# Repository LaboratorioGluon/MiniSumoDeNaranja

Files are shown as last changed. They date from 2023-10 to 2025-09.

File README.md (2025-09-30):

# MiniSumoDeNaranja
Minisumo para la competición OSHDEM 2023.

Hecho integramente en los directos de twitch (www.twitch.tv/labgluon)

# Hardware

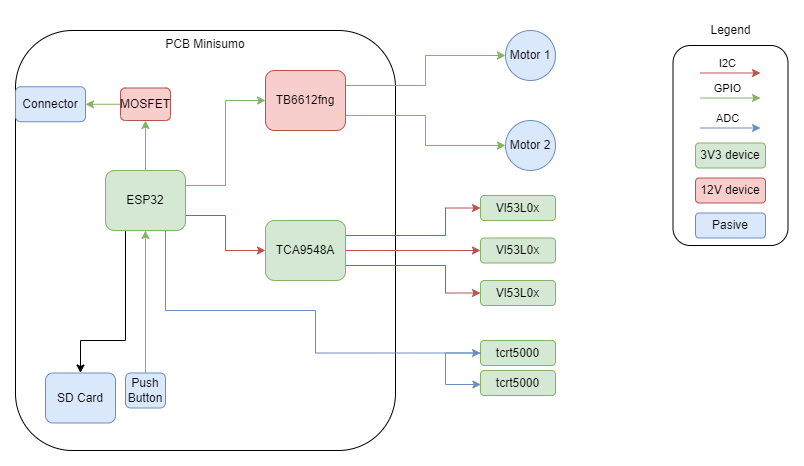
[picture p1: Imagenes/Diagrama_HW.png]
Diagrama HW


## Componentes (fuera de la PCB):
- Sensores IR (TCRT5000) https://s.click.aliexpress.com/e/_DeqiwYr
- Sensores ToF (VL53L0X) https://s.click.aliexpress.com/e/_DDpGy5Z
- Motores (N20 200RPM) https://s.click.aliexpress.com/e/_DkiL8JH
- ESP32 (ESP32-WROOM-32D) https://s.click.aliexpress.com/e/_DlMmuSj

## Configuracion pines

| 1 | 2 | 3 | 4 | Modo |
|-|-|-|-|-|
| 0 | 0 | 0 | 0 | FWD  |
| 1 | 0 | 0 | 0 | RIGHT|
| 0 | 1 | 0 | 0 | LEFT |

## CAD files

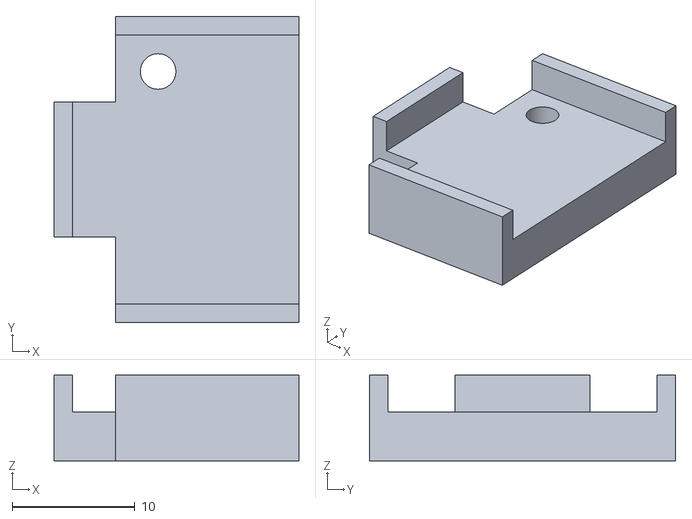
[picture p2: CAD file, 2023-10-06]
3D/Sujeccion_Alimentacion.stl
20.0 x 25.0 x 7.00

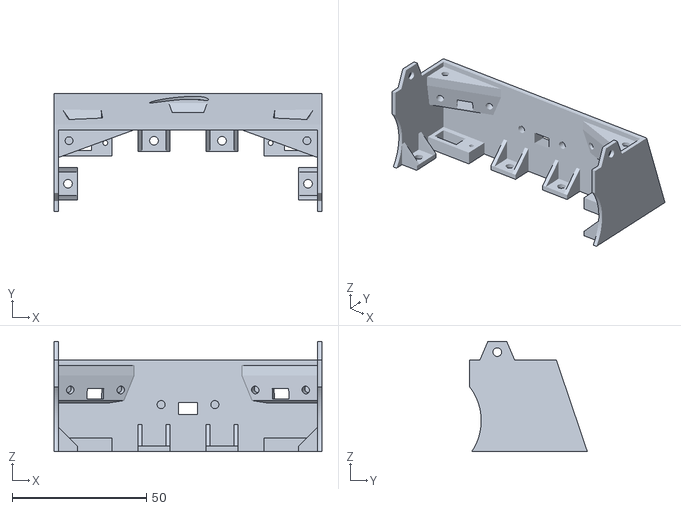
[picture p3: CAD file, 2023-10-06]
3D/Frontal.stl
99.7 x 43.8 x 41.0

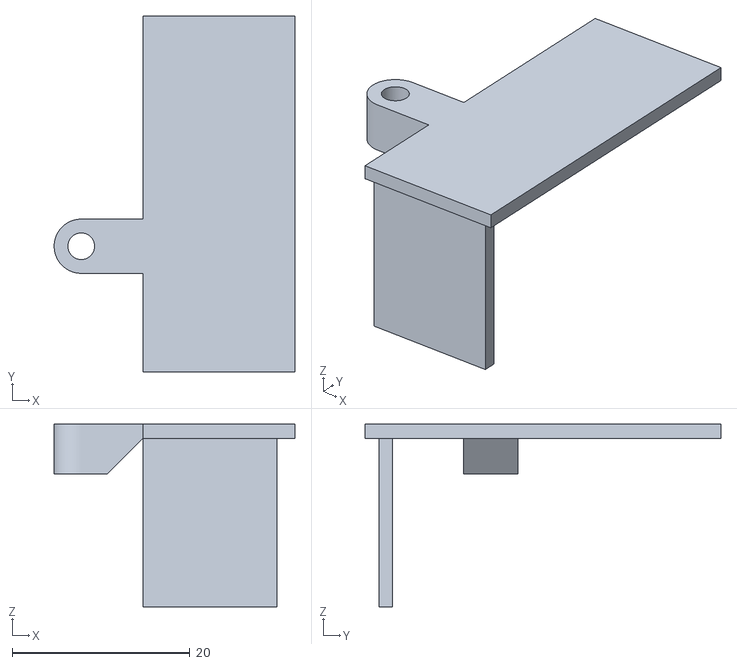
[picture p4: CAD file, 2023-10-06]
3D/SujeccionBateria.stl
27.1 x 40.1 x 20.6

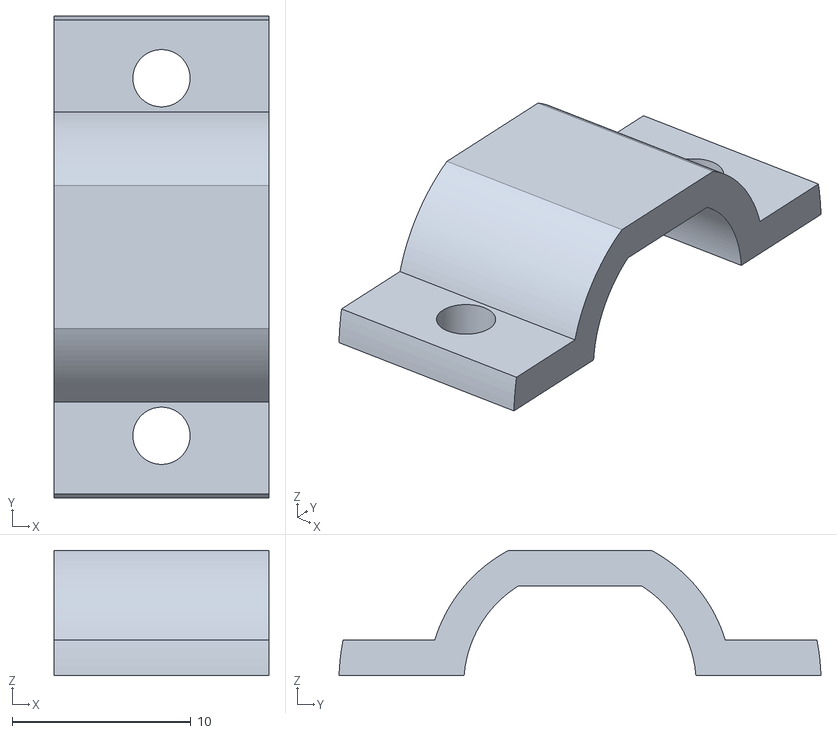
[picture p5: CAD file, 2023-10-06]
3D/Base_N20_Holder.stl
12.0 x 27.0 x 7.00

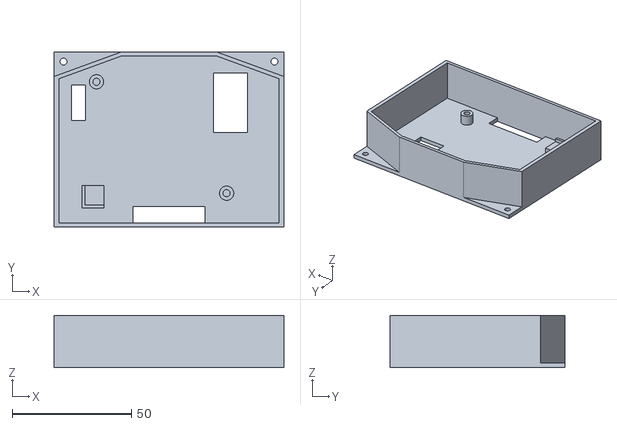
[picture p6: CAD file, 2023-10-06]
3D/Superior.stl
96.5 x 73.4 x 22.0

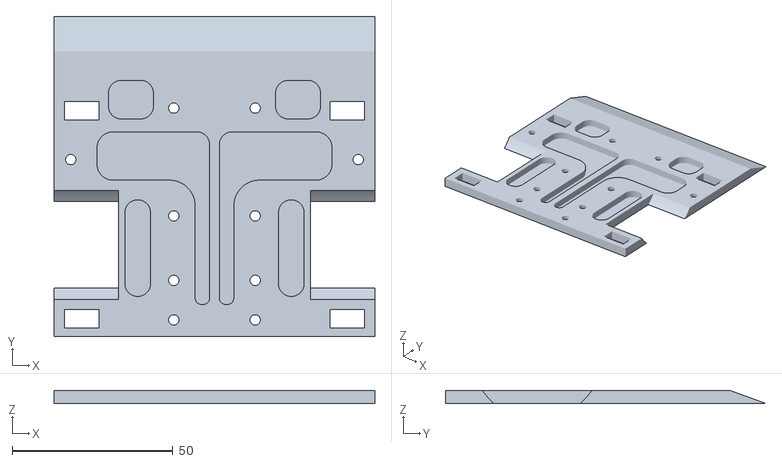
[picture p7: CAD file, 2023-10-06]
3D/Base_bottom.stl
99.7 x 99.5 x 4.00

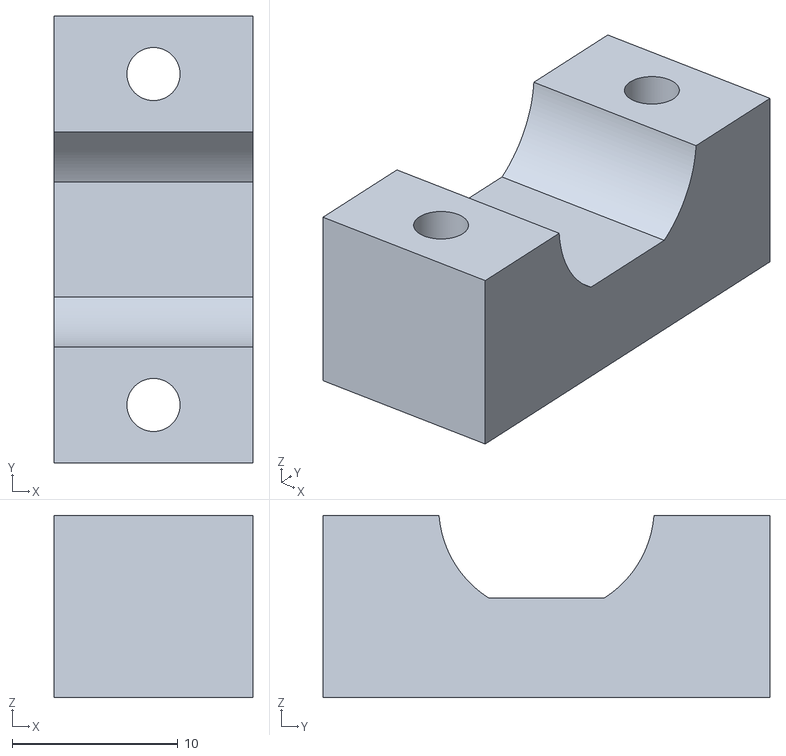
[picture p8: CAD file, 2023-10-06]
3D/Base_N20_Base.stl
12.0 x 27.0 x 11.0

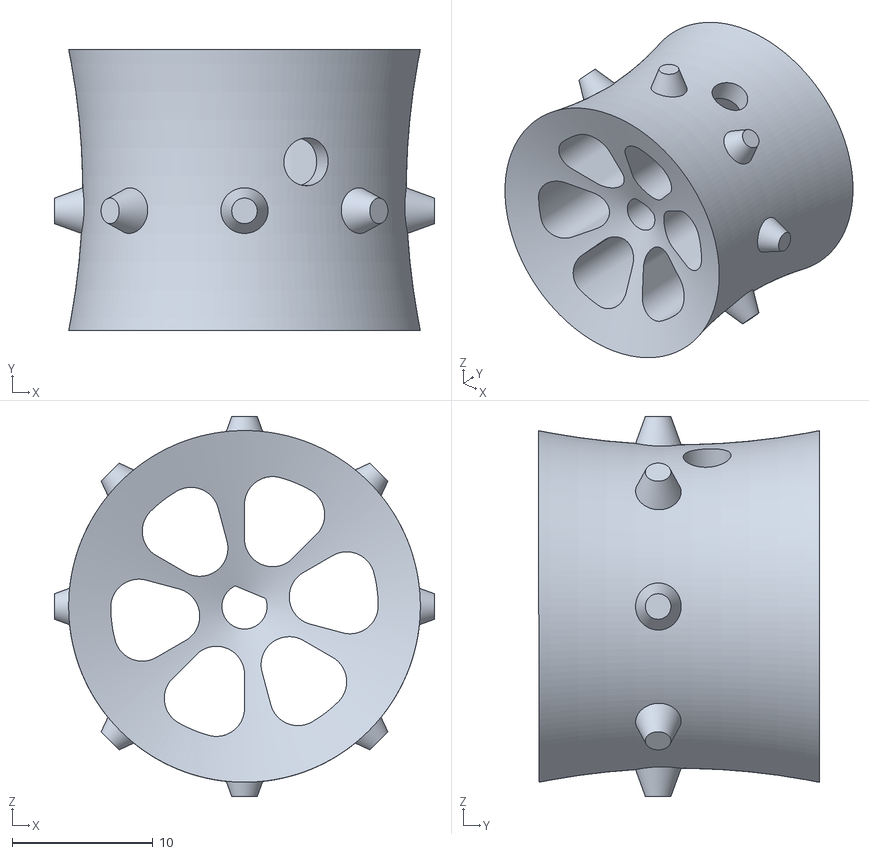
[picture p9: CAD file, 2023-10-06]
3D/Rueda - Llanta.stl
27.0 x 20.0 x 27.0

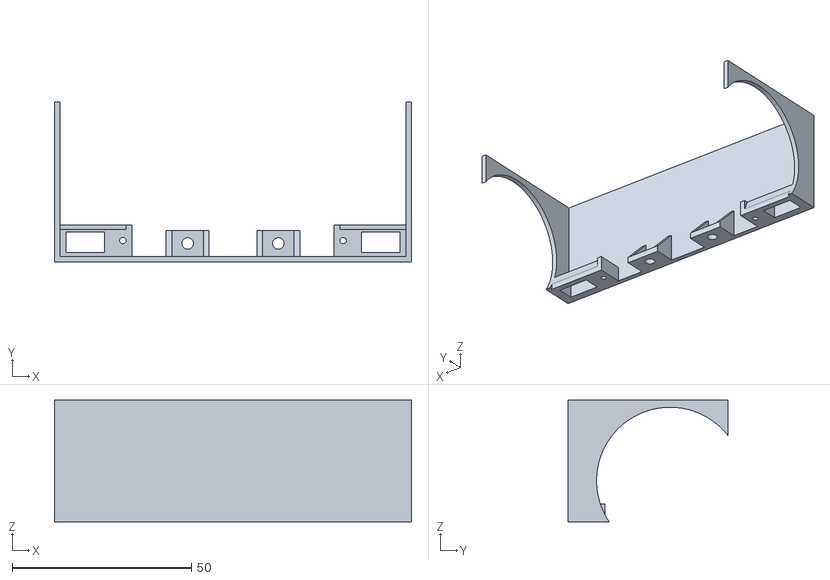
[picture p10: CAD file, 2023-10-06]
3D/Trasera.stl
99.7 x 44.7 x 34.0

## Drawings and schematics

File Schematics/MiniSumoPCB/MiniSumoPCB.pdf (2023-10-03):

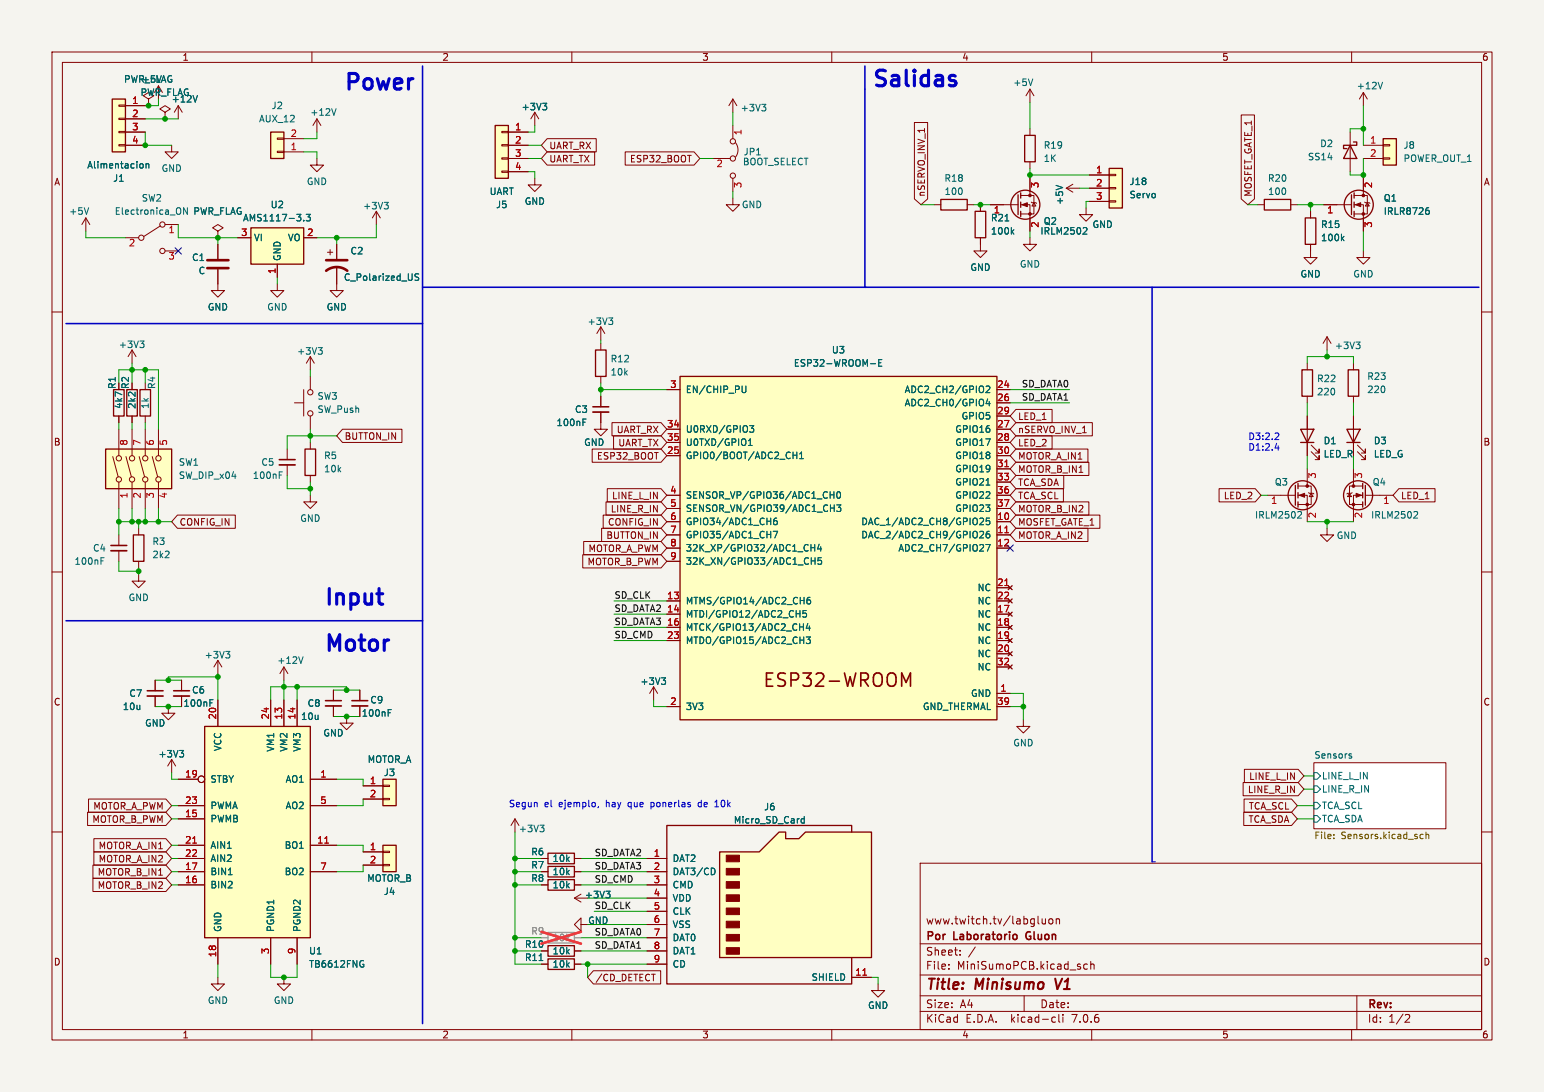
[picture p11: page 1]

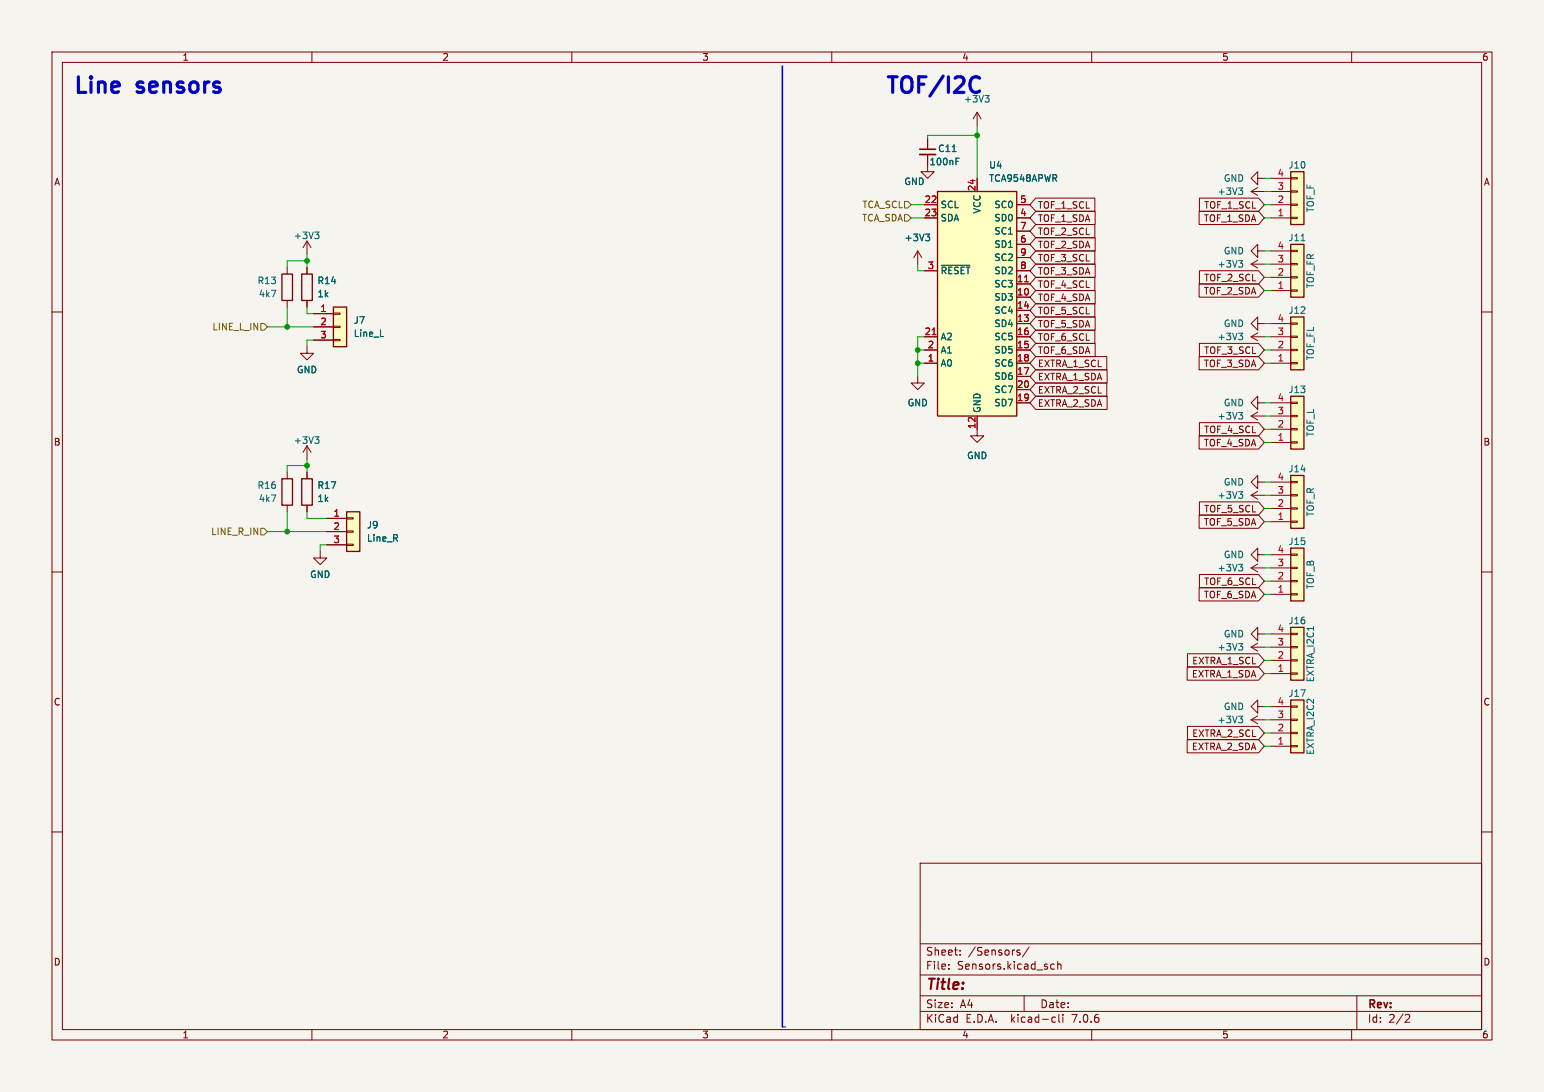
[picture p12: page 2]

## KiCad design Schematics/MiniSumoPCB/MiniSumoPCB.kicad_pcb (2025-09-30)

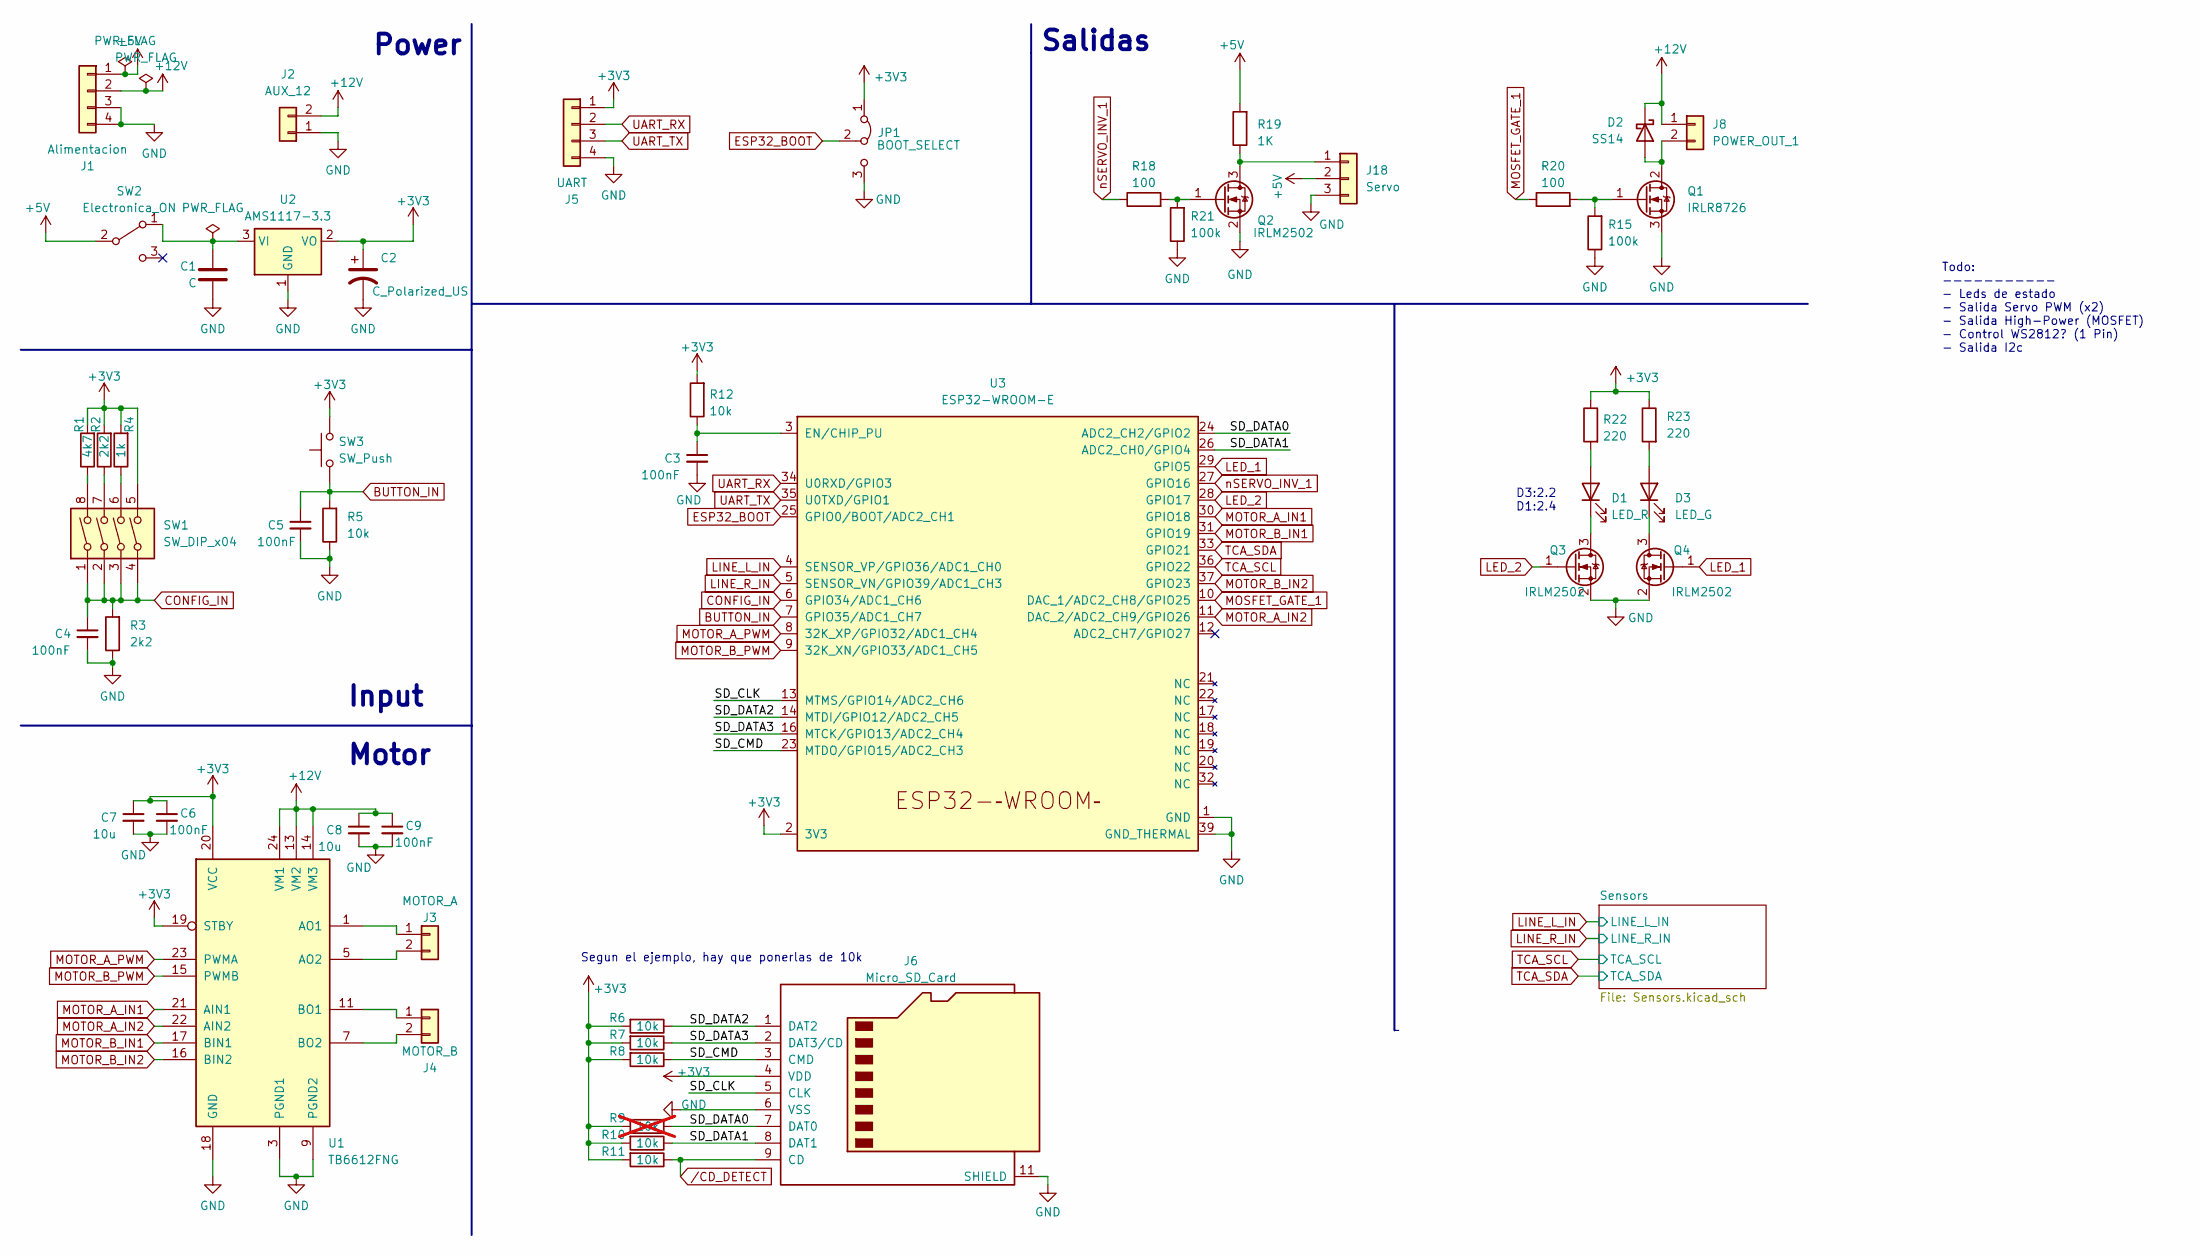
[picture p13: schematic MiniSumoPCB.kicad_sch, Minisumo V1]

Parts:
C1: C; C_1206_3216Metric_Pad1.33x1.80mm_HandSolder
C2: C_Polarized_US; CP_Elec_4x5.3
C3, C4, C5, C6, C9: 100nF; C_1206_3216Metric_Pad1.33x1.80mm_HandSolder
C7, C8: 10u; C_1206_3216Metric_Pad1.33x1.80mm_HandSolder
D1: LED_R; LED_1210_3225Metric_Pad1.42x2.65mm_HandSolder
D2: SS14; D_SMA_Handsoldering
D3: LED_G; LED_1210_3225Metric_Pad1.42x2.65mm_HandSolder
J1: Alimentacion; JST_PH_B4B-PH-K_1x04_P2.00mm_Vertical
J2: AUX_12; S2B-XH-SM4-TB
J3: MOTOR_A; S2B-XH-SM4-TB
J4: MOTOR_B; S2B-XH-SM4-TB
J5: UART; PinHeader_1x04_P2.54mm_Vertical
J6: Micro_SD_Card; microSD-Receptacle-SelfEject
J8: POWER_OUT_1; S2B-XH-SM4-TB
J18: Servo; PinHeader_1x03_P2.54mm_Vertical
JP1: BOOT_SELECT; PinHeader_1x03_P2.54mm_Vertical
Q1: IRLR8726; TO-252-2
Q2, Q3, Q4: IRLM2502; SOT-23
R1: 4k7; R_1206_3216Metric_Pad1.30x1.75mm_HandSolder
R2, R3: 2k2; R_1206_3216Metric_Pad1.30x1.75mm_HandSolder
R4: 1k; R_1206_3216Metric_Pad1.30x1.75mm_HandSolder
R5, R6, R7, R8, R10, R11, R12: 10k; R_1206_3216Metric_Pad1.30x1.75mm_HandSolder
R9: 10k; R_1206_3216Metric_Pad1.30x1.75mm_HandSolder; not fitted
R15, R21: 100k; R_1206_3216Metric_Pad1.30x1.75mm_HandSolder
R18, R20: 100; R_1206_3216Metric_Pad1.30x1.75mm_HandSolder
R19: 1K; R_1206_3216Metric_Pad1.30x1.75mm_HandSolder
R22, R23: 220; R_1206_3216Metric_Pad1.30x1.75mm_HandSolder
SW1: SW_DIP_x04; SW_DIP_SPSTx04_Slide_9.78x12.34mm_W7.62mm_P2.54mm
SW2: Electronica_ON; SS12D07VG2
SW3: SW_Push; SKPMANE010 _Silicone_6x6mm
U1: TB6612FNG; SSOP-24_5.3x8.2mm_P0.65mm
U2: AMS1117-3.3; SOT-223-3_TabPin2
U3: ESP32-WROOM-E; ESP32-WROOM-32E

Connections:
+3V3: C2.1, C6.1, C7.1, J5.1, J6.4 (VDD), JP1.1 (A), R1.2, R2.2, R4.2, R6.2, R7.2, R8.2, R9.2, R10.2, R11.2, R12.2, R22.1, R23.1, SW1.5, SW3.2, U1.19 (STBY), U1.20 (VCC), U2.2 (VO), U3.2 (3V3); also elsewhere on the board
+5V: J1.1, J18.2, R19.2, SW2.2 (B)
+12V: C8.1, C9.1, D2.1 (K), J1.2, J2.2, J8.1, U1.13 (VM2), U1.14 (VM3), U1.24 (VM1)
/SD_CLK: J6.5 (CLK), U3.13 (MTMS/GPIO14/ADC2_CH6)
/SD_CMD: J6.3 (CMD), R8.1, U3.23 (MTDO/GPIO15/ADC2_CH3)
/SD_DATA0: J6.7 (DAT0), R9.1, U3.24 (ADC2_CH2/GPIO2)
/SD_DATA1: J6.8 (DAT1), R10.1, U3.26 (ADC2_CH0/GPIO4)
/SD_DATA2: J6.1 (DAT2), R6.1, U3.14 (MTDI/GPIO12/ADC2_CH5)
/SD_DATA3: J6.2 (DAT3/CD), R7.1, U3.16 (MTCK/GPIO13/ADC2_CH4)
BUTTON_IN: C5.1, R5.2, SW3.1, U3.7 (GPIO35/ADC1_CH7)
CONFIG_IN: C4.1, R3.2, SW1.1, SW1.2, SW1.3, SW1.4, U3.6 (GPIO34/ADC1_CH6)
ESP32_BOOT: JP1.2 (C), U3.25 (GPIO0/BOOT/ADC2_CH1)
GND: C1.2, C2.2, C3.2, C4.2, C5.2, C6.2, C7.2, C8.2, C9.2, J1.3, J1.4, J2.1, J5.4, J6.6 (VSS), J6.11 (SHIELD), J18.3, JP1.3 (B), Q1.3 (S), Q2.2 (S), Q3.2 (S), Q4.2 (S), R3.1, R5.1, R15.1, R21.1, U1.3 (PGND1), U1.4 (PGND1), U1.9 (PGND2), U1.10 (PGND2), U1.18 (GND), U2.1 (GND), U3.1 (GND), U3.15 (GND), U3.38 (GND), U3.39 (GND_THERMAL); also elsewhere on the board
LED_1: Q4.1 (G), U3.29 (GPIO5)
LED_2: Q3.1 (G), U3.28 (GPIO17)
LINE_L_IN: U3.4 (SENSOR_VP/GPIO36/ADC1_CH0); also elsewhere on the board
LINE_R_IN: U3.5 (SENSOR_VN/GPIO39/ADC1_CH3); also elsewhere on the board
MOSFET_GATE_1: R20.1, U3.10 (DAC_1/ADC2_CH8/GPIO25)
MOTOR_A_IN1: U1.21 (AIN1), U3.30 (GPIO18)
MOTOR_A_IN2: U1.22 (AIN2), U3.11 (DAC_2/ADC2_CH9/GPIO26)
MOTOR_A_PWM: U1.23 (PWMA), U3.8 (32K_XP/GPIO32/ADC1_CH4)
MOTOR_B_IN1: U1.17 (BIN1), U3.31 (GPIO19)
MOTOR_B_IN2: U1.16 (BIN2), U3.37 (GPIO23)
MOTOR_B_PWM: U1.15 (PWMB), U3.9 (32K_XN/GPIO33/ADC1_CH5)
unnamed: D1.2 (A), R22.2
unnamed: D1.1 (K), Q3.3 (D)
unnamed: D2.2 (A), J8.2, Q1.2 (D)
unnamed: D3.2 (A), R23.2
unnamed: D3.1 (K), Q4.3 (D)
unnamed: J3.1, U1.1 (AO1), U1.2 (AO1)
unnamed: J3.2, U1.5 (AO2), U1.6 (AO2)
unnamed: J4.1, U1.11 (BO1), U1.12 (BO1)
unnamed: J4.2, U1.7 (BO2), U1.8 (BO2)
unnamed: J18.1, Q2.3 (D), R19.1
unnamed: Q1.1 (G), R15.2, R20.2
unnamed: Q2.1 (G), R18.2, R21.2
unnamed: R1.1, SW1.8
unnamed: R2.1, SW1.7
unnamed: R4.1, SW1.6
unnamed: C1.1, SW2.1 (A), U2.3 (VI)
unnamed: C3.1, R12.1, U3.3 (EN/CHIP_PU)
TCA_SCL: U3.36 (GPIO22); also elsewhere on the board
TCA_SDA: U3.33 (GPIO21); also elsewhere on the board
UART_RX: J5.2, U3.34 (U0RXD/GPIO3)
UART_TX: J5.3, U3.35 (U0TXD/GPIO1)
nSERVO_INV_1: R18.1, U3.27 (GPIO16)
/CD_DETECT: J6.9 (CD), R11.1

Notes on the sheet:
Motor
Segun el ejemplo, hay que ponerlas de 10k
Power
Salidas
D3:2.2 D1:2.4
Todo: ----------- - Leds de estado - Salida Servo PWM (x2) - Salida High-Power (MOSFET) - Control WS2812? (1 Pin) - Salida I2c
Input

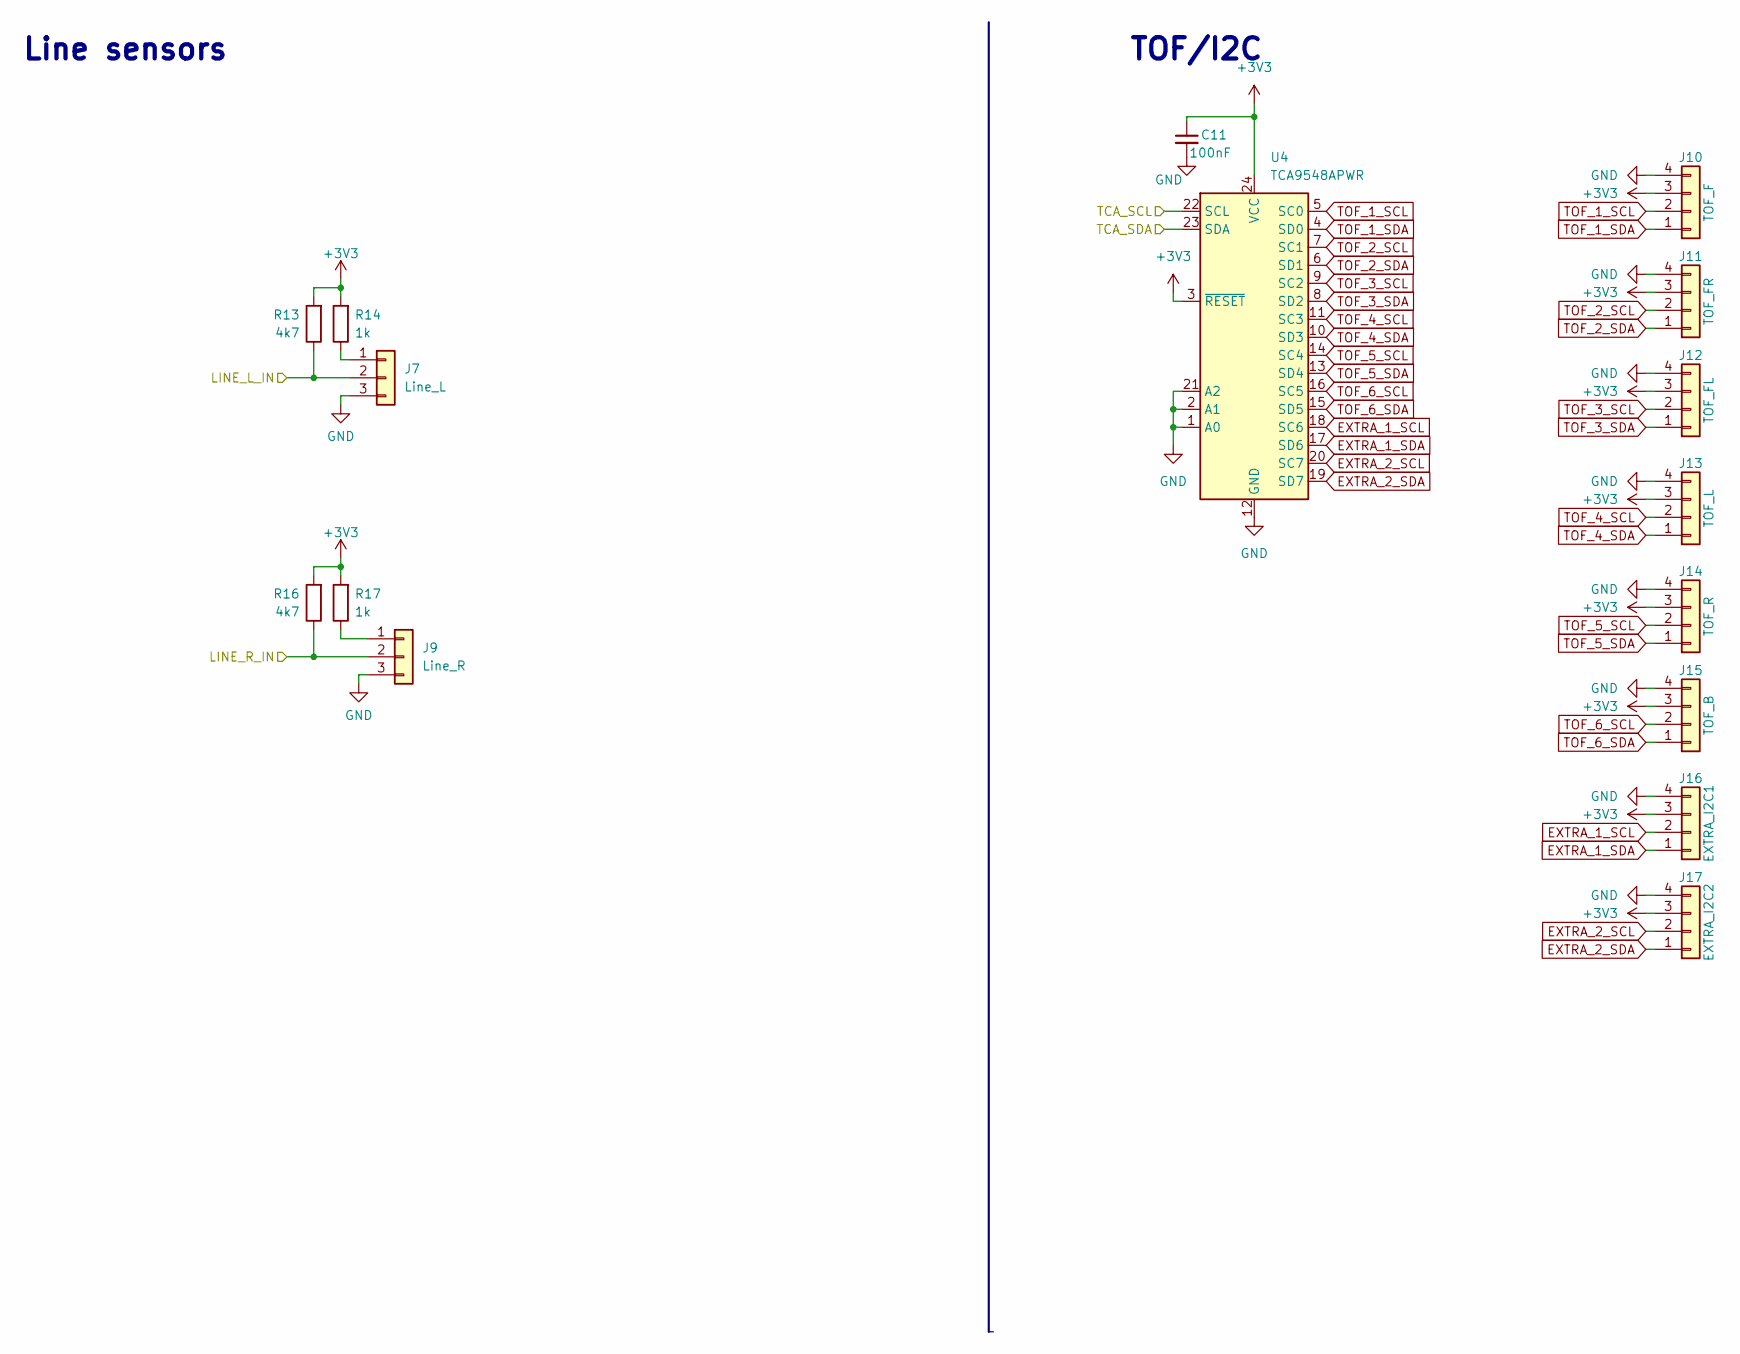
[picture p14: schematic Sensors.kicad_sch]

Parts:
C11: 100nF; C_1206_3216Metric_Pad1.33x1.80mm_HandSolder
J7: Line_L; JST_PH_B3B-PH-K_1x03_P2.00mm_Vertical
J9: Line_R; JST_PH_B3B-PH-K_1x03_P2.00mm_Vertical
J10: TOF_F; JST_PH_B4B-PH-K_1x04_P2.00mm_Vertical
J11: TOF_FR; JST_PH_B4B-PH-K_1x04_P2.00mm_Vertical
J12: TOF_FL; JST_PH_B4B-PH-K_1x04_P2.00mm_Vertical
J13: TOF_L; JST_PH_B4B-PH-K_1x04_P2.00mm_Vertical
J14: TOF_R; JST_PH_B4B-PH-K_1x04_P2.00mm_Vertical
J15: TOF_B; JST_PH_B4B-PH-K_1x04_P2.00mm_Vertical
J16: EXTRA_I2C1; JST_PH_B4B-PH-K_1x04_P2.00mm_Vertical
J17: EXTRA_I2C2; JST_PH_B4B-PH-K_1x04_P2.00mm_Vertical
R13, R16: 4k7; R_1206_3216Metric_Pad1.30x1.75mm_HandSolder
R14, R17: 1k; R_1206_3216Metric_Pad1.30x1.75mm_HandSolder
U4: TCA9548APWR; TSSOP-24_4.4x7.8mm_P0.65mm

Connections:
+3V3: C11.1, J10.3, J11.3, J12.3, J13.3, J14.3, J15.3, J16.3, J17.3, R13.2, R14.2, R16.2, R17.2, U4.3 (~RESET), U4.24 (VCC); also elsewhere on the board
EXTRA_1_SCL: J16.2, U4.18 (SC6)
EXTRA_1_SDA: J16.1, U4.17 (SD6)
EXTRA_2_SCL: J17.2, U4.20 (SC7)
EXTRA_2_SDA: J17.1, U4.19 (SD7)
GND: C11.2, J7.3, J9.3, J10.4, J11.4, J12.4, J13.4, J14.4, J15.4, J16.4, J17.4, U4.1 (A0), U4.2 (A1), U4.12 (GND), U4.21 (A2); also elsewhere on the board
LINE_L_IN: J7.2, R13.1; also elsewhere on the board
LINE_R_IN: J9.2, R16.1; also elsewhere on the board
unnamed: J7.1, R14.1
unnamed: J9.1, R17.1
TCA_SCL: U4.22 (SCL); also elsewhere on the board
TCA_SDA: U4.23 (SDA); also elsewhere on the board
TOF_1_SCL: J10.2, U4.5 (SC0)
TOF_1_SDA: J10.1, U4.4 (SD0)
TOF_2_SCL: J11.2, U4.7 (SC1)
TOF_2_SDA: J11.1, U4.6 (SD1)
TOF_3_SCL: J12.2, U4.9 (SC2)
TOF_3_SDA: J12.1, U4.8 (SD2)
TOF_4_SCL: J13.2, U4.11 (SC3)
TOF_4_SDA: J13.1, U4.10 (SD3)
TOF_5_SCL: J14.2, U4.14 (SC4)
TOF_5_SDA: J14.1, U4.13 (SD4)
TOF_6_SCL: J15.2, U4.16 (SC5)
TOF_6_SDA: J15.1, U4.15 (SD5)

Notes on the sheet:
Line sensors
TOF/I2C

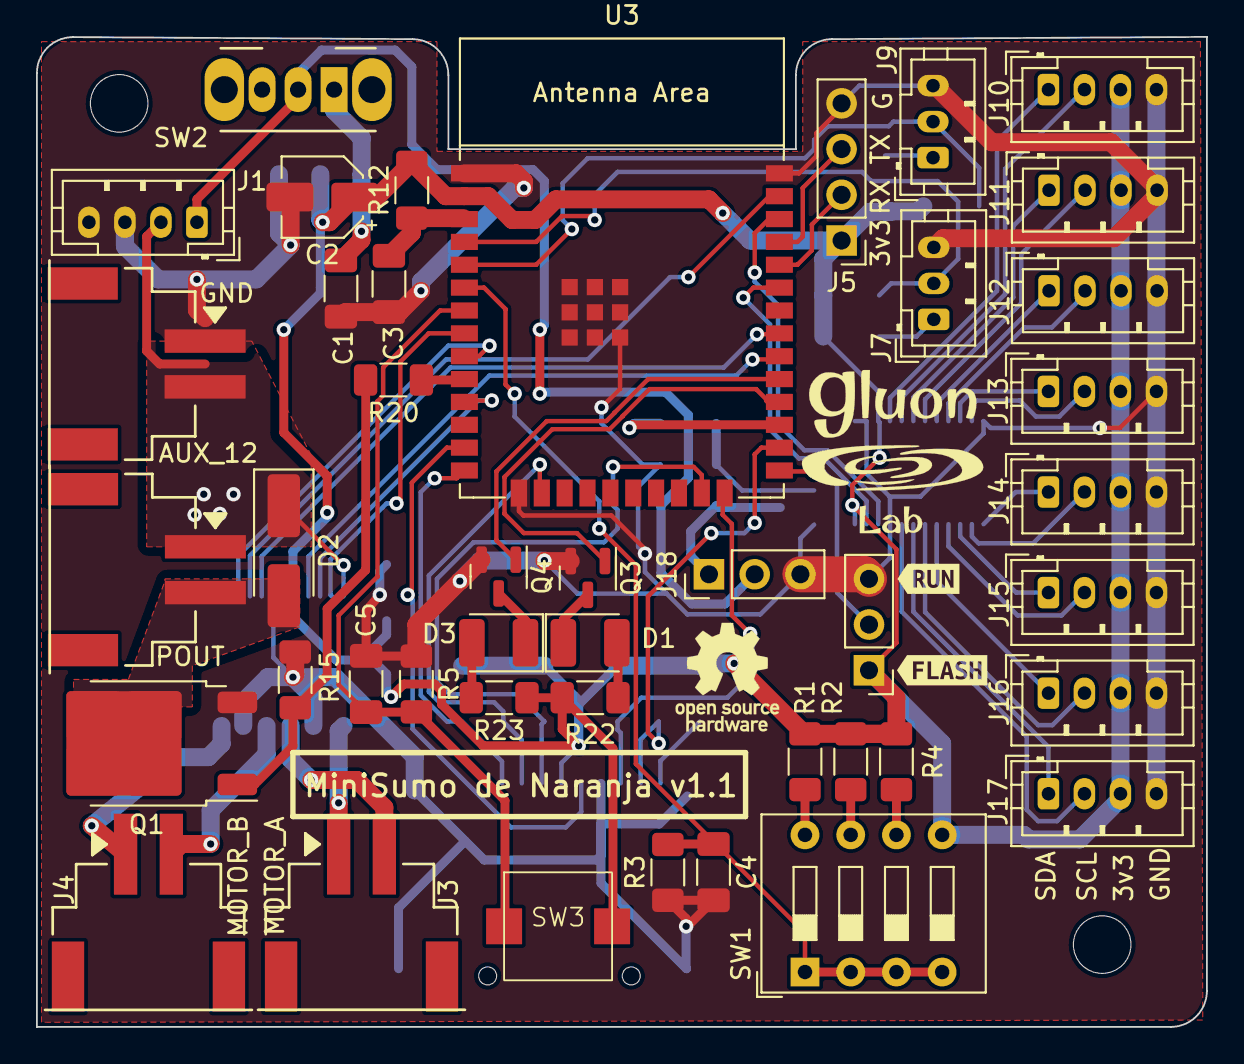
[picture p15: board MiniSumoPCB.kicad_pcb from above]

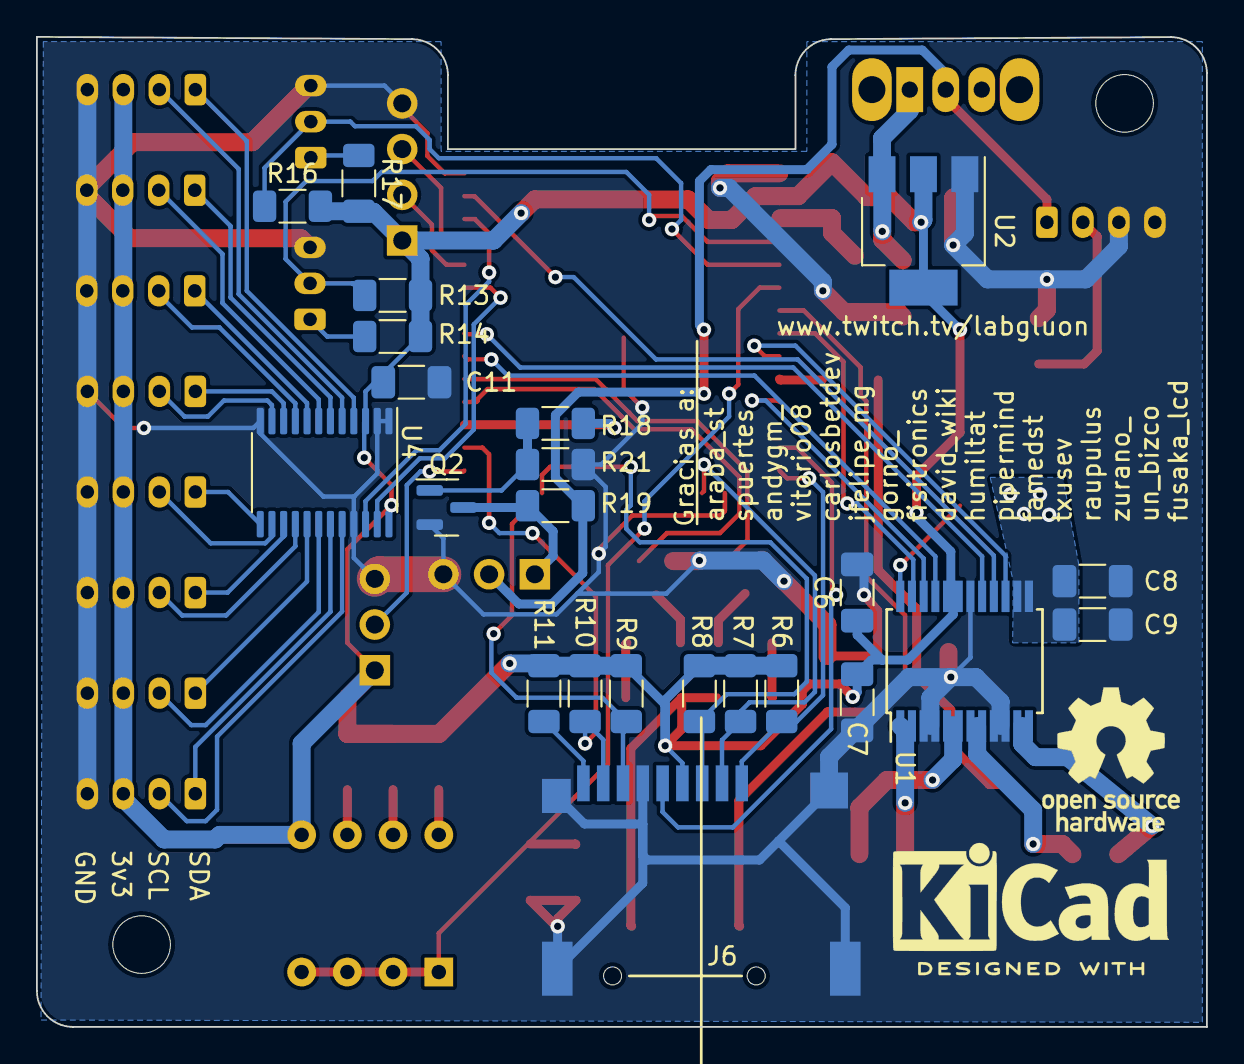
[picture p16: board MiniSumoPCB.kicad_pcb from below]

Board: 2 copper layers, 65.0 x 55.0 mm, 68 parts (23 on the bottom side), 65 nets.

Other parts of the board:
kibuzzard-63F11F4E: G***; kibuzzard-63F11F4E
kibuzzard-63F11F5A: G***; kibuzzard-63F11F5A

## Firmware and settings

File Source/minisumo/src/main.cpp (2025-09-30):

#include <freertos/FreeRTOS.h>
#include <freertos/timers.h>
#include <esp_timer.h>
#include <esp_http_client.h>
#include <nvs_flash.h>
#include <esp_https_ota.h>
#include <esp_log.h>
// #include <driver/adc.h>
#include <esp_adc/adc_continuous.h>
#include <driver/adc.h>
#include <stdint.h>

#include "hwInterface.h"
#include "motorController.h"
#include "vl53l0x.h"
#include "labVl53l0x.h"
#include "commander.h"
#include "i2cExpander.h"
#include "sensors.h"
#include "configLoader.h"
#include "informer.h"

#include "secret.h"

static char TAG[] = "MAIN";

// #define ENABLE_OTA

#ifdef ENABLE_OTA
extern "C" void wifi_init_sta();
#endif

#ifndef WIFI_PWD
#error Missing WIFI_PWD Environment variable
#endif

#ifndef WIFI_SSID
#error Missing WIFI_SSID Environment variable
#endif

extern "C" void app_main();

#define MOTOR_PIN_1 GPIO_NUM_5
#define MIN_TOF_VALUE 20

uint16_t rangeMeasurement = 0;

MotorController motors(PIN_MOTOR_A_IN1, PIN_MOTOR_A_IN2, PIN_MOTOR_A_PWM, PIN_MOTOR_B_IN1, PIN_MOTOR_B_IN2, PIN_MOTOR_B_PWM);
labVL53L0X rangeSensor;
Sensors sensors;
Commander commander;
Informer informer(PIN_LED_1, PIN_LED_2);
uint16_t tofSensorData[NUM_TOF_SENSORS];
uint32_t lineSensorData[NUM_LINE_SENSORS];
uint32_t lineStartValue[NUM_LINE_SENSORS];

uint64_t lastmicros;
uint8_t isRotating = 0;
int64_t remainingRotation = 0;
uint32_t isEnemyDown = 0;

uint8_t isrTriggered = 0;

static TaskHandle_t initTask = NULL;
static TaskHandle_t mainCoreHandle = NULL;
static TaskHandle_t sensorCoreHandle = NULL;

static void IRAM_ATTR gpio_isr_handler(void *arg)
{
    isrTriggered = 1;
    if (initTask != NULL)
    {
        vTaskNotifyGiveFromISR(initTask, NULL);
    }
}

enum STARTUP_CONFIG
{
    START_INVALID_CONFIG = -1,
    START_ENEMY_FWD = 0, // 0000
    START_ENEMY_RIGHT,   // 0001
    START_ENEMY_LEFT,    // 0010
    START_ENEMY_BACK,    // 0011
} startupConfig;

// Micro FSM Moore
enum STATES
{
    SEARCHING = 0,
    ATTACKING,
    EVADING
};

void EnableWifi()
{
#ifdef ENABLE_OTA
    wifi_init_sta();
#endif
}

enum STATES currentState = SEARCHING;
int64_t currentStateStart = 0;

void startRotating(uint64_t rotatingTime)
{
    lastmicros = esp_timer_get_time();
    remainingRotation = rotatingTime;
    isRotating = 1;
}

void Init()
{
    initTask = xTaskGetCurrentTaskHandle();

    esp_err_t err = nvs_flash_init();
    if (err == ESP_ERR_NVS_NO_FREE_PAGES || err == ESP_ERR_NVS_NEW_VERSION_FOUND)
    {
        ESP_ERROR_CHECK(nvs_flash_erase());
        err = nvs_flash_init();
    }
    ESP_ERROR_CHECK(err);

    informer.Init();
    informer.setStatus(Informer::STARTING);

    motors.Init();
    sensors.Init();

    EnableWifi();

    startupConfig = (STARTUP_CONFIG)loadConfig();

    if (startupConfig == START_INVALID_CONFIG)
    {
        // Todo: Inform with LED.
        ESP_LOGE(TAG, "Error invalid config!");
    }
    else
    {
        ESP_LOGE(TAG, "Current config: %d", startupConfig);
    }

    gpio_config_t io_conf = {};

    // Configure pins for MotorA
    io_conf.intr_type = GPIO_INTR_POSEDGE;
    io_conf.mode = GPIO_MODE_INPUT;
    io_conf.pin_bit_mask = (1ULL << GPIO_NUM_35);
    io_conf.pull_down_en = GPIO_PULLDOWN_DISABLE;
    io_conf.pull_up_en = GPIO_PULLUP_DISABLE;
    gpio_config(&io_conf);
    gpio_set_level(GPIO_NUM_35, 1);

    gpio_install_isr_service(0);
    gpio_isr_handler_add(GPIO_NUM_35, gpio_isr_handler, nullptr);

    informer.setStatus(Informer::WAITING_PUSH_BUTTON);
    ulTaskNotifyTake(pdTRUE, portMAX_DELAY);
    ESP_LOGE(TAG, "Triggered!!");
    informer.setStatus(Informer::WAITING_5S);
    // Wait 5 seconds mandatory by the rules.
    vTaskDelay(pdMS_TO_TICKS(5000));
    informer.setStatus(Informer::RUNNING);
    ESP_LOGE(TAG, "Robot encendido");

    // Store line value
    sensors.updateLine();
    sensors.getLine(lineSensorData);
    lineStartValue[0] = lineSensorData[0];
    lineStartValue[1] = lineSensorData[1];

    ESP_LOGE(TAG, "Valor linea inicio: %lu, %lu", lineStartValue[0], lineStartValue[1]);

    switch (startupConfig)
    {
    case START_INVALID_CONFIG:
        break;
    case START_ENEMY_FWD:
        break;
    case START_ENEMY_RIGHT:
        motors.setDirection(MotorController::RIGHT);
        startRotating(300000);
        break;
    case START_ENEMY_LEFT:
        motors.setDirection(MotorController::LEFT);
        startRotating(300000);
        break;
    case START_ENEMY_BACK:
        motors.setDirection(MotorController::RIGHT);
        startRotating(600000);
        break;
    }
}

inline uint8_t isTofActivated(uint8_t index)
{
    return ((tofSensorData[index] > 30) && (tofSensorData[index] < 650));
}

inline uint8_t isLineActivated(uint8_t index)
{
    return lineSensorData[index] < lineStartValue[index] * 0.5;
}

void loopSearching();
void loopAttack();
void loopEvading();

typedef void (*func_t)();
func_t funcs[] = {
    loopSearching,
    loopAttack,
    loopEvading};

uint8_t prevLineActivated[NUM_LINE_SENSORS] = {0, 0};

void changeState(enum STATES newState)
{
    currentState = newState;
    currentStateStart = esp_timer_get_time();

    funcs[currentState]();
}

void loopEvading()
{
    if (esp_timer_get_time() > currentStateStart + 1000000)
    {
        changeState(SEARCHING);
    }
}



void attackCheckLine()
{
    if (isLineActivated(0))
    {
        motors.setDirection(MotorController::BACK);
        vTaskDelay(pdMS_TO_TICKS(100));
        //ESP_LOGE(TAG, "ATK LINE SENSOR 0 ACTIVATED");
        motors.setDirection(MotorController::LEFT);
        startRotating(300000);
    }
    else if (isLineActivated(1))
    {
        motors.setDirection(MotorController::BACK);
        vTaskDelay(pdMS_TO_TICKS(100));
        //ESP_LOGE(TAG, "ATK LINE SENSOR 1 ACTIVATED");
        motors.setDirection(MotorController::RIGHT);
        startRotating(300000);
    }
}

void loopAttack()
{

    informer.setStatus(Informer::TARGET_ADQUIRED);

    if (isTofActivated(0))
    {
        motors.setDirection(MotorController::FWD);
        //ESP_LOGE(TAG, "ATTACK: NORMAL FWD");
        attackCheckLine();

        /*if (prevLineActivated[0] == 0 && prevLineActivated[1] == 0)
        {
            // This condition marks the start of the fuck off strategy
            if (isLineActivated(0)) // Right sensor activated for the first time
            {
                ESP_LOGE(TAG, "ATTACK: Activado 0");
                prevLineActivated[0] = 1;
                motors.setDirection(MotorController::BACK);
                vTaskDelay(pdMS_TO_TICKS(50));
            }
            else if (isLineActivated(1)) // Left sensor activated for the first time
            {
                ESP_LOGE(TAG, "ATTACK: Activado 1");
                prevLineActivated[1] = 1;
                motors.setDirection(MotorController::BACK);
                vTaskDelay(pdMS_TO_TICKS(50));
            }
        }
        else
        {
            if (prevLineActivated[0])
            {
                motors.setDirection(MotorController::RIGHT);
                if (isLineActivated(1))
                {
                    ESP_LOGE(TAG, "ATTACK: Fin Activado 1");
                    prevLineActivated[0] = 0;
                    prevLineActivated[1] = 0;
                    motors.setDirection(MotorController::BACK);
                    vTaskDelay(pdMS_TO_TICKS(300));
                    startRotating(300000);
                }
            }
            else
            {
                motors.setDirection(MotorController::LEFT);
                if (isLineActivated(0))
                {
                    ESP_LOGE(TAG, "ATTACK: Fin Activado 0");
                    prevLineActivated[0] = 0;
                    prevLineActivated[1] = 0;
                    motors.setDirection(MotorController::BACK);
                    vTaskDelay(pdMS_TO_TICKS(300));
                    startRotating(300000);
                }
            }
        }*/
    }
    else if (isTofActivated(1))
    {
        //ESP_LOGE(TAG, "ATTACK: NORMAL LEFT");
        motors.setDirection(MotorController::LEFT);
        attackCheckLine();
    }
    else if (isTofActivated(2))
    {
        //ESP_LOGE(TAG, "ATTACK: NORMAL RIGHT");
        motors.setDirection(MotorController::RIGHT);
        attackCheckLine();
    }

    if (
        !isTofActivated(0) &&
        !isTofActivated(1) &&
        !isTofActivated(2))
    {
        /*ESP_LOGE(TAG, "Switching to SEARCH MODE");
        ESP_LOGE(TAG, "%d, %d, %d", isTofActivated(0), isTofActivated(1), isTofActivated(2));
        ESP_LOGE(TAG, "Sensor: %lu, %lu, %lu", tofSensorData[0], tofSensorData[1], tofSensorData[2]);*/
        changeState(SEARCHING);
    }
}

void loopRotating()
{
    if (remainingRotation <= 0)
    {
        // Volvemos a ir recto
        ESP_LOGE(TAG, "End rotating");
        isRotating = 0;
        isEnemyDown = 0;
    }
    remainingRotation -= esp_timer_get_time() - lastmicros;
    lastmicros = esp_timer_get_time();
}

void loopSearching()
{
    informer.setStatus(Informer::RUNNING);
    if (isEnemyDown == 0)
    {
        if (isTofActivated(0) ||
            isTofActivated(1) ||
            isTofActivated(2))
        {
            /*ESP_LOGE(TAG, "Switching to ATTACK MODE");
            ESP_LOGE(TAG, "%d, %d, %d", isTofActivated(0), isTofActivated(1), isTofActivated(2));
            ESP_LOGE(TAG, "Sensor: %lu, %lu, %lu", tofSensorData[0], tofSensorData[1], tofSensorData[2]);*/
            changeState(ATTACKING);
        }
    }

    if (!isRotating)
    {
        motors.setDirection(MotorController::FWD);
        if (isLineActivated(0))
        {
            motors.setDirection(MotorController::BACK);
            vTaskDelay(pdMS_TO_TICKS(100));
            ESP_LOGE(TAG, "LINE SENSOR 0 ACTIVATED");
            motors.setDirection(MotorController::LEFT);
            startRotating(300000);
        }
        else if (isLineActivated(1))
        {
            motors.setDirection(MotorController::BACK);
            vTaskDelay(pdMS_TO_TICKS(100));
            ESP_LOGE(TAG, "LINE SENSOR 1 ACTIVATED");
            motors.setDirection(MotorController::RIGHT);
            startRotating(300000);
        }
    }
    else
    {
        loopRotating();
    }
}

enum CMD
{
    NOTHING = 0,
    FWD,
    BACK,
    RIGHT,
    LEFT,
    CONTINUE, // sigue el proceso normal
    LAUNCH_MISSILE,
    END_CIVILIZATION_WITH_NUKE_RED_BUTTON_ADMIN_123,
    UPDATE_FW
};

void updateOTA()
{
    ESP_LOGI(TAG, "Starting OTA example task");
    esp_http_client_config_t config = {
        .url = "http://192.168.1.133:8000/firmware.bin?", // Cambialo por la URL donde estará tu binario compilado
        .keep_alive_enable = true,
    };

    esp_https_ota_config_t ota_config = {
        .http_config = &config,
    };
    ESP_LOGI(TAG, "Attempting to download update from %s", config.url);
    esp_err_t ret = esp_https_ota(&ota_config);
    if (ret == ESP_OK)
    {
        ESP_LOGI(TAG, "OTA Succeed, Rebooting...");
        esp_restart();
    }
    else
    {
        ESP_LOGE(TAG, "Firmware upgrade failed");
    }
    while (1)
    {
        vTaskDelay(1000 / portTICK_PERIOD_MS);
    }
}

uint8_t commandRunning; // If 0 : Do normal execution, otherwise, dont do the main loop
void doCommand()
{

    char lastCommand[50];
    commander.updateCommand();
    commander.getLastCommand(lastCommand, 50);

    if (!strcmp(lastCommand, "UPDATE_FW"))
    {
        ESP_LOGE(TAG, "NEW VERSION!!!");
        commandRunning = 1;
        motors.setDirection(MotorController::STOP);
        updateOTA();
    }
    else if (!strcmp(lastCommand, "FWD"))
    {
        commandRunning = 1;
        ESP_LOGE(TAG, "Setting Direction: FWD");
        motors.setDirection(MotorController::FWD);
    }
    else if (!strcmp(lastCommand, "BACK"))
    {
        commandRunning = 1;
        ESP_LOGE(TAG, "Setting Direction: BACK");
        motors.setDirection(MotorController::BACK);
    }
    else if (!strcmp(lastCommand, "RIGHT"))
    {
        commandRunning = 1;
        ESP_LOGE(TAG, "Setting Direction: RIGHT");
        motors.setDirection(MotorController::RIGHT);
    }
    else if (!strcmp(lastCommand, "LEFT"))
    {
        commandRunning = 1;
        ESP_LOGE(TAG, "Setting Direction: LEFT");
        motors.setDirection(MotorController::LEFT);
    }
    else if (!strcmp(lastCommand, "CONTINUE"))
    {
        commandRunning = 0;
        ESP_LOGE(TAG, "Command continue");
        motors.setDirection(MotorController::STOP);
    }
}
// Fin Micro FSM

void coreAThread(void *arg)
{
    static uint64_t lastmicros = esp_timer_get_time();
    ESP_LOGE(TAG, "Iniciando CORE A");

    while (true)
    {
        sensors.getTof(tofSensorData);
        sensors.getLine(lineSensorData);

        // ESP_LOGE(TAG,"Sensor: %lu, %lu, %lu", tofSensorData[0], tofSensorData[1], tofSensorData[2]);
        //ESP_LOGE(TAG, "Lineas :%lu, %lu", lineSensorData[0], lineSensorData[1]);

        if (!commandRunning)
        {
            // loop of current state
            funcs[currentState]();
        }

#ifdef ENABLE_OTA
        // Recibir comandos y autoactualizarnos
        if (esp_timer_get_time() > lastmicros + 500000)
        {
            doCommand();
            lastmicros = esp_timer_get_time();
        }
        counter++;
#endif

        taskYIELD();
    }
}

void coreBThread(void *arg)
{
    ESP_LOGE(TAG, "Iniciando CORE B");
    while (true)
    {
        sensors.updadeTof();
        sensors.updateLine();
        vTaskDelay(pdMS_TO_TICKS(2));
    }
}

void app_main()
{
    ESP_LOGE(TAG, "Iniciando software");

    Init();

    xTaskCreatePinnedToCore(coreBThread, "Sensor_Core", 4096, NULL, 9, &sensorCoreHandle, 1);
    xTaskCreatePinnedToCore(coreAThread, "Main_core", 4096, NULL, 10, &mainCoreHandle, 0);
    
    
}

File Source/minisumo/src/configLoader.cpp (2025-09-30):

#include "configLoader.h"
#include <esp_log.h>

#include "driver/adc.h"

const char TAG[]= "CONFIG";

int8_t loadConfig()
{
    adc1_config_width(ADC_WIDTH_BIT_12);
    adc1_config_channel_atten(ADC1_CHANNEL_6, ADC_ATTEN_DB_11);
    
    // Get configuration
    uint32_t adc_raw=0;
    for(uint8_t i =0; i < 10; i++){
        adc_raw += adc1_get_raw(ADC1_CHANNEL_6);
    }
    adc_raw /= 10;
    ESP_LOGE(TAG, "Raw value: %lu", adc_raw);

    int8_t configuration = -1;

    if(adc_raw < 200) // 0000
    {
        configuration = 0;
    }
    else if(adc_raw < 1506) // 0001
    {
        configuration = 1;
    }
    else if ( adc_raw < 2065) // 0010
    {
        configuration = 2;
    }
    else if ( adc_raw < 2441) // 0011
    {
        configuration = 3;
    }
    else if (adc_raw < 2708) // 0100
    {
        // Intentionally empty
    }
    else if (adc_raw < 2194) // 0101
    {
        // Intentionally empty    
    }
    else if( adc_raw < 2362) // 0110
    {
        // Intentionally empty
    }
    else if ( adc_raw < 3270) // 0111
    {
        // Intentionally empty
    }
    else //1XXX
    {
        // Intentionally empty
    }

    return configuration;
}

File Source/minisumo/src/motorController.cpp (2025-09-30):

#include "motorController.h"
#include <driver/ledc.h>


MotorController::MotorController(gpio_num_t motorA1_, gpio_num_t motorA2_, gpio_num_t motorAPwm_, 
                                 gpio_num_t motorB1_, gpio_num_t motorB2_, gpio_num_t motorBPwm_ )
{
    motorA1 = motorA1_;
    motorA2 = motorA2_;
    motorAPwm = motorAPwm_;
    motorB1 = motorB1_;
    motorB2 = motorB2_;
    motorBPwm = motorBPwm_;
}

void MotorController::Init()
{
    gpio_config_t io_conf = {};

    // Configure pins for MotorA
    io_conf.intr_type = GPIO_INTR_DISABLE;
    io_conf.mode = GPIO_MODE_OUTPUT;
    io_conf.pin_bit_mask = (1ULL << motorA1) | (1ULL << motorA2) | (1ULL << motorAPwm);
    io_conf.pull_down_en = GPIO_PULLDOWN_DISABLE;
    io_conf.pull_up_en = GPIO_PULLUP_DISABLE;
    gpio_config(&io_conf);

    // Configure pins for MotorB
    io_conf.intr_type = GPIO_INTR_DISABLE;
    io_conf.mode = GPIO_MODE_OUTPUT;
    io_conf.pin_bit_mask = (1ULL << motorB1) | (1ULL << motorB2) | (1ULL << motorBPwm);
    io_conf.pull_down_en = GPIO_PULLDOWN_DISABLE;
    io_conf.pull_up_en = GPIO_PULLUP_DISABLE;
    gpio_config(&io_conf);

    gpio_set_level(motorA1, 0);
    gpio_set_level(motorA2, 0);
    //gpio_set_level(motorAPwm, 1);
    gpio_set_level(motorB1, 0);
    gpio_set_level(motorB2, 0);
    //gpio_set_level(motorBPwm, 1);

    // Prepare and then apply the LEDC PWM timer configuration
    ledc_timer_config_t ledc_timer = {
        .speed_mode       = LEDC_LOW_SPEED_MODE,
        .duty_resolution  = LEDC_TIMER_10_BIT ,
        .timer_num        = LEDC_TIMER_0,
        .freq_hz          = 10000,  // Set output frequency at 10 kHz
        .clk_cfg          = LEDC_AUTO_CLK
    };
    ESP_ERROR_CHECK(ledc_timer_config(&ledc_timer));

    // Prepare and then apply the LEDC PWM channel configuration
    ledc_channel_config_t ledc_channel = {
        .gpio_num       = motorAPwm,
        .speed_mode     = LEDC_LOW_SPEED_MODE,
        .channel        = LEDC_CHANNEL_0,
        .intr_type      = LEDC_INTR_DISABLE,
        .timer_sel      = LEDC_TIMER_0,
        .duty           = 0, // Set duty to 0%
        .hpoint         = 0
    };
    ESP_ERROR_CHECK(ledc_channel_config(&ledc_channel));

    ledc_channel.gpio_num = motorBPwm;
    ledc_channel.channel = LEDC_CHANNEL_1;
    ESP_ERROR_CHECK(ledc_channel_config(&ledc_channel));



    // Set duty to 50%
    ESP_ERROR_CHECK(ledc_set_duty(LEDC_LOW_SPEED_MODE, LEDC_CHANNEL_0, 1024));
    ESP_ERROR_CHECK(ledc_set_duty(LEDC_LOW_SPEED_MODE, LEDC_CHANNEL_1, 1024));
    // Update duty to apply the new value
    ESP_ERROR_CHECK(ledc_update_duty(LEDC_LOW_SPEED_MODE, LEDC_CHANNEL_0));
    ESP_ERROR_CHECK(ledc_update_duty(LEDC_LOW_SPEED_MODE, LEDC_CHANNEL_1));

}


void MotorController::setDirection(DIRECTION dir)
{
    switch(dir)
    {
        case DIRECTION::STOP: 
            gpio_set_level(motorA1, 1);
            gpio_set_level(motorA2, 1);
            gpio_set_level(motorB1, 1);
            gpio_set_level(motorB2, 1);
            break;
        case DIRECTION::BACK: 
            gpio_set_level(motorA1, 1);
            gpio_set_level(motorA2, 0);
            gpio_set_level(motorB1, 1);
            gpio_set_level(motorB2, 0);
            break;
        case DIRECTION::RIGHT: 
            gpio_set_level(motorA1, 0);
            gpio_set_level(motorA2, 1);
            gpio_set_level(motorB1, 1);
            gpio_set_level(motorB2, 0);
            break;
        case DIRECTION::LEFT: 
            gpio_set_level(motorA1, 1);
            gpio_set_level(motorA2, 0);
            gpio_set_level(motorB1, 0);
            gpio_set_level(motorB2, 1);
            break;
        case DIRECTION::FWD: 
            gpio_set_level(motorA1, 0);
            gpio_set_level(motorA2, 1);
            gpio_set_level(motorB1, 0);
            gpio_set_level(motorB2, 1);
        break;
    }
}

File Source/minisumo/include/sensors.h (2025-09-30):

#ifndef __SENSORS_H__
#define __SENSORS_H__

#define NUM_TOF_SENSORS 3
#define NUM_LINE_SENSORS 2

#include <freertos/FreeRTOS.h>
#include <freertos/semphr.h>

#include "i2cExpander.h"
#include "labVl53l0x.h"

class Sensors{
public:
    Sensors();

    void Init();

    void getTof(uint16_t _tofData[NUM_TOF_SENSORS]);
    void getLine(uint32_t _lineData[NUM_LINE_SENSORS]);


    void updadeTof();
    void updateLine();

private:
    SemaphoreHandle_t semaphore_;
    labVL53L0X rangeSensor;
    
    i2cExpander tca;

    uint32_t tofRateValue[NUM_TOF_SENSORS] = {70,70,80};
    uint32_t tofThresholdValue[NUM_TOF_SENSORS] = {95,95,98};

    uint32_t lastTofValues[NUM_TOF_SENSORS] = {0,0,0};

    /* Critical sections */
    uint16_t tofData[NUM_TOF_SENSORS];
    uint32_t lineData[NUM_LINE_SENSORS];

};

#endif //__SENSORS_H__

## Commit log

2023-08-13 Added PCB design
    [MiniSumoPCB.kicad_pcb, MiniSumoPCB.kicad_sch, Sensors.kicad_sch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]
2023-08-14 Added new subs to PCB
    [MiniSumoPCB.kicad_pcb]
2023-08-14 [PCB] Added decoupling Capacitors
    [MiniSumoPCB.kicad_pcb, MiniSumoPCB.kicad_sch, Sensors.kicad_sch]
2023-08-15 [PCB] Update minor version
    [MiniSumoPCB.kicad_pcb]
2023-08-20 Two cores and mutex working
    [MiniSumoPCB.kicad_pcb, MiniSumoPCB.kicad_sch]
2023-08-20 Tof sensor data used in FSM
2023-09-15 Added Tb661.. driver and push button detection
2023-09-15 Added LED information
2023-09-21 Working sensors and wheel! First robot build
2023-09-24 Forking line sensor avoidance
    [configLoader.cpp, main.cpp, motorController.cpp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]
2023-10-03 Added HW schematic
2023-10-03 Target tracking
    [MiniSumoPCB.kicad_sch, Sensors.kicad_sch]
2023-10-06 Added 3d model parts
    [Base_N20_Base.stl, Base_N20_Holder.stl, Base_bottom.stl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]
2023-12-16 Resistor Ladder
